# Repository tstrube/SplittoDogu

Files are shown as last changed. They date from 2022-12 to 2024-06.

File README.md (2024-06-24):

# SplittoDogu
QMK firmware for split keyboard with screens and encoders

This is a split keyboard with encoders for arrow keys, mouse wheels, page up/down, and undo/redo.
One of the two screens shows the active layer and status of Num and Caps. The other screen is for Bongo Cat...

It's also possible to use one side only. (Garming or Macro Keyboard)

Optional components: screens, encoder, buttons...

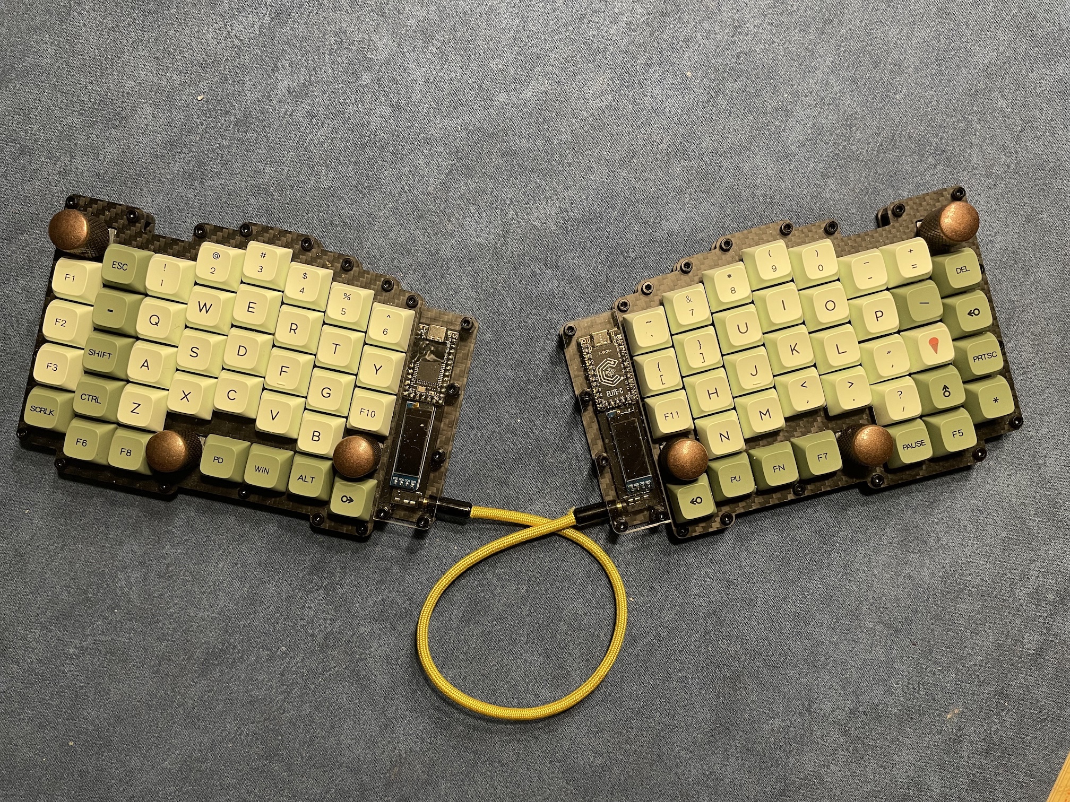
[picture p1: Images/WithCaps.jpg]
Splitto Dogu with Caps

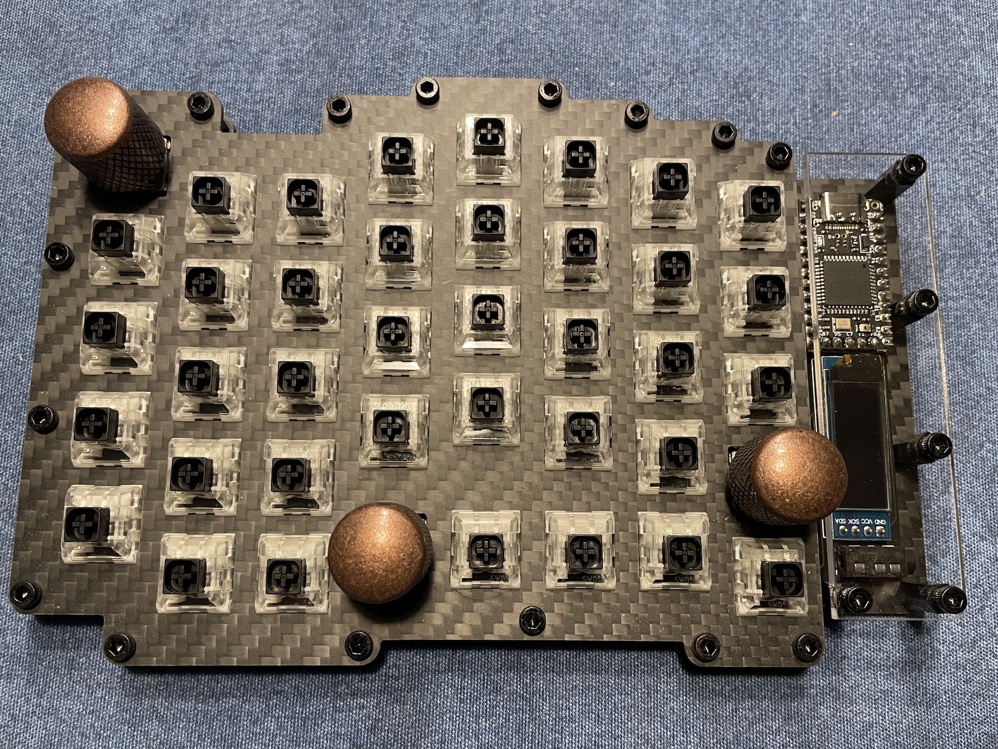
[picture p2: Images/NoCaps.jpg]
Splitto Dogu without Caps


## Layouts
There are two nearly identical default layouts. One for Windows and the other for MAC.
The differences are key combinations for undo/redo and other hotkeys.

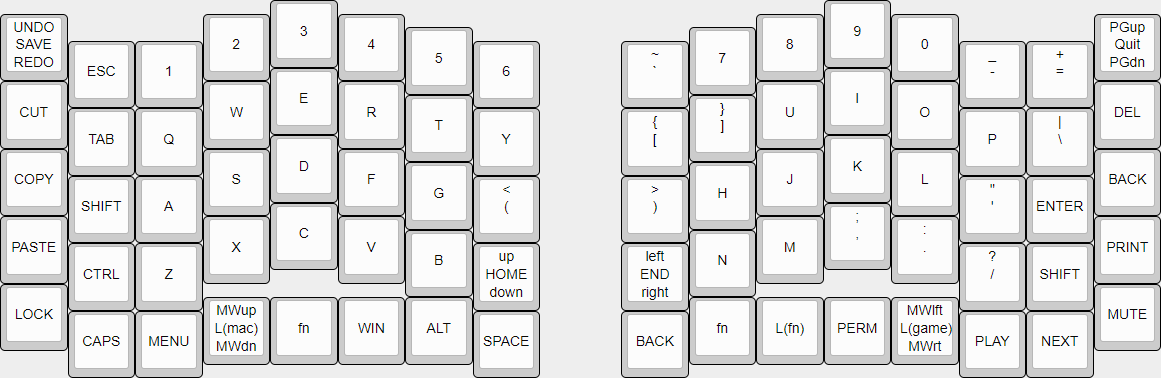
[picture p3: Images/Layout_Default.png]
Splitto Dogu Layout Default


Next is a layer for gaming, which shifts most buttons on the left half to the right by one key.
This is moves WASD to the optimal position.

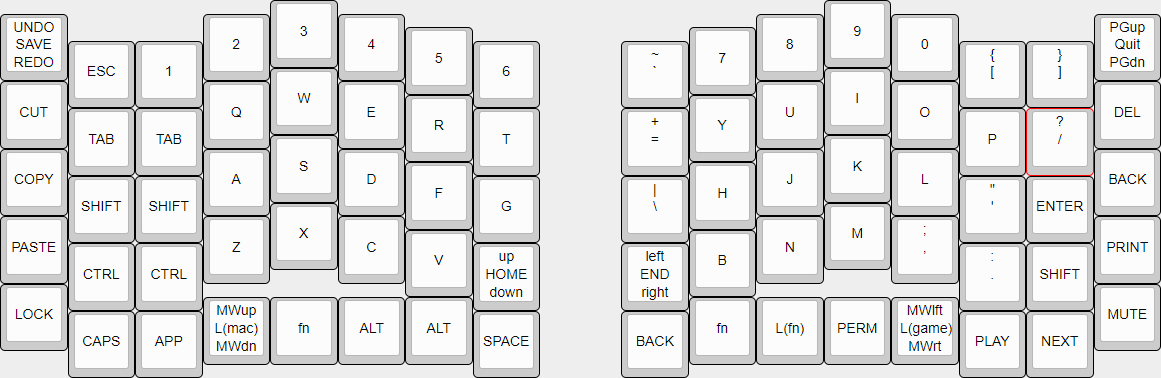
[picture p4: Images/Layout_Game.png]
Splitto Dogu Layout Game


The last layer FN is for F1 to F12, arrow keys, and the keypad.

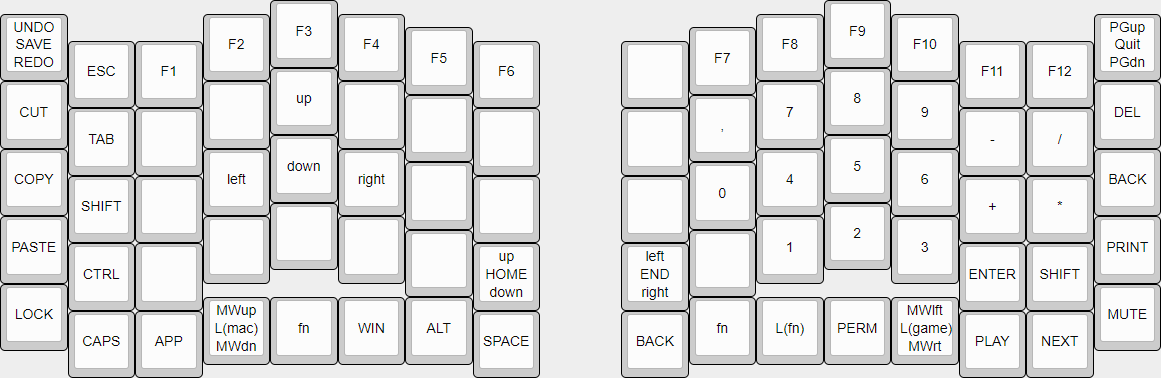
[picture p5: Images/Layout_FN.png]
Splitto Dogu Layout FN


## PCB
The PCB can be used for both sides. It's possible to use one half without the other.
So select which side a board is used for, bridge the jumper points under the OLED screen.
JP_L1 to JP_L6 for the left side, JP_R1 to JP_R6 for the right.
The Elite-C must be flipped depending on the side. (See images)

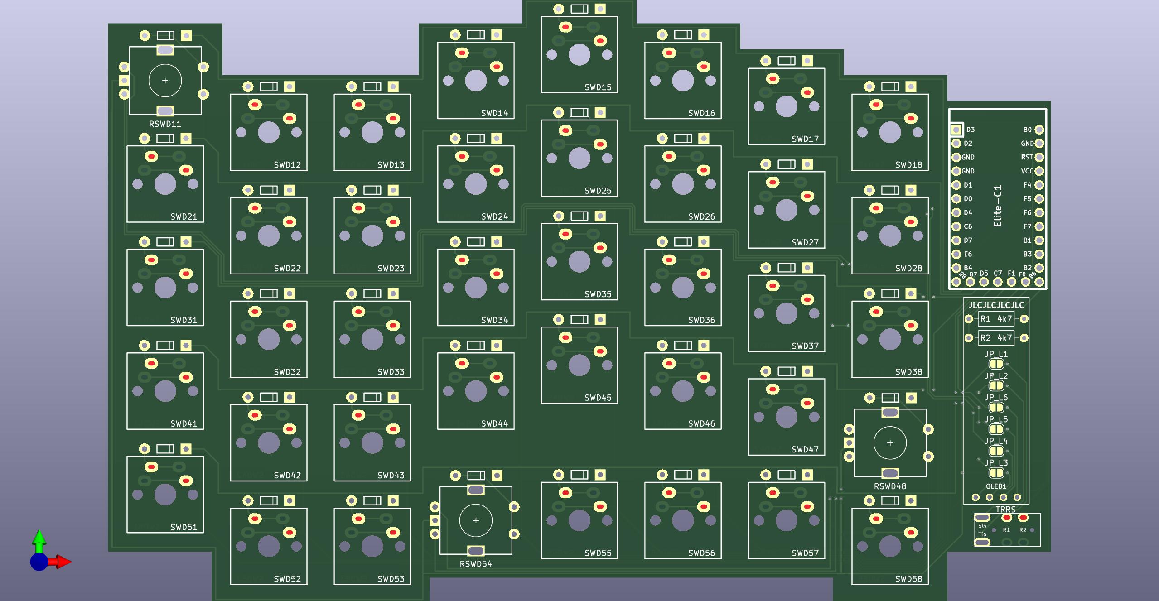
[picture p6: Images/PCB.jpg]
Splitto Dogu PCB

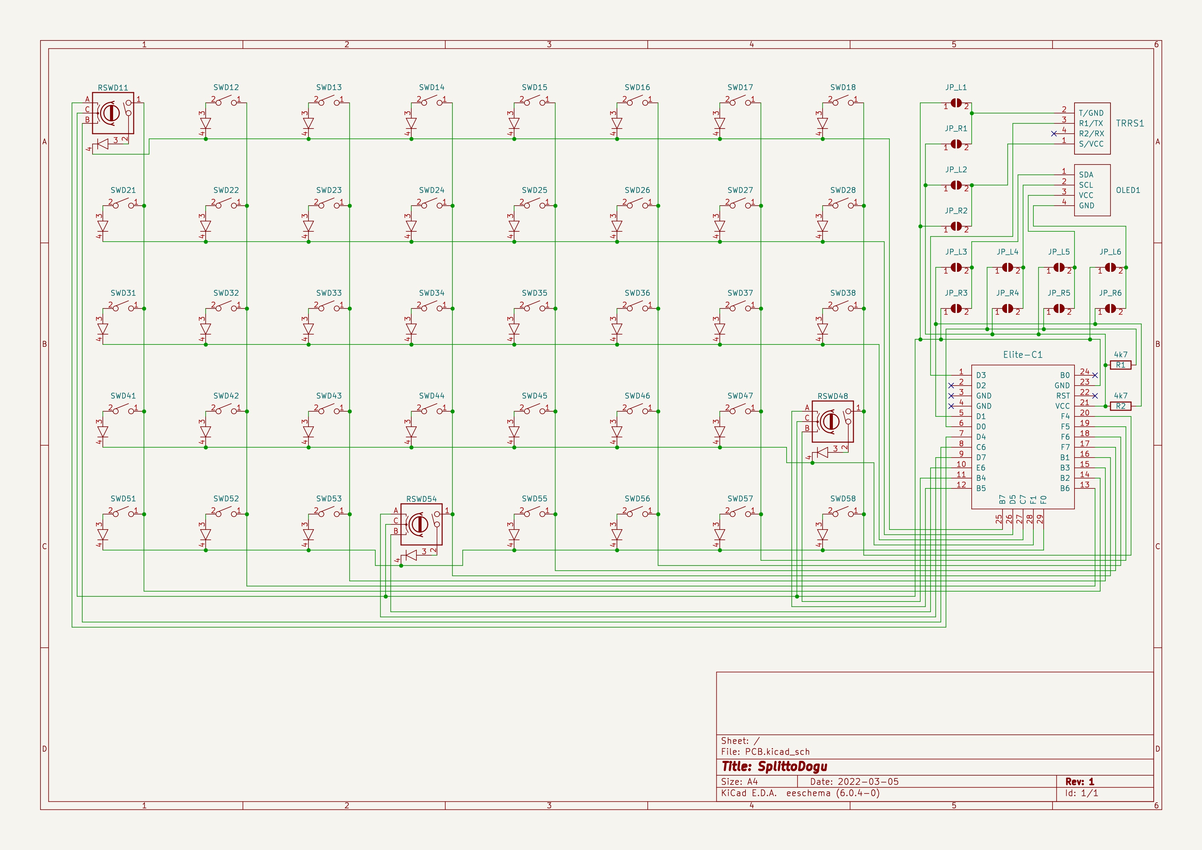
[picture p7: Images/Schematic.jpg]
Splitto Dogu Schematic


## Case
The case is a simple sandwich case with a clear part covering the chip and screen.
The main case uses 8mm standoffs, while the clear part uses 11mm. (See BOM)

## BOM
A list with all parts used and their approximate price as of March 2022.

## Crypto Donations

- **BTC:** bc1qqa9skjw0av0dnpzl53dhapgllw9nxpr3e3ncg6
- **DOGE:** D6Skk3K4H8KZWc7WcG69Ki5mkXc3f8pscc
- **ETH:** 0x7370eD840A690010eEF5726D71eEa54a9F45A202
- **SOL:** FipyS8kETFE8XRMkDez1nRRNe1n94Etws15UQfvzRsgg
- **XCH:** xch10t2jmnrnq8295pxqdtvn4pp5dgdcm7aar5usz0e4e57xyyjegtuqxwtq9z

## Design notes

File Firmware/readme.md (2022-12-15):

# splittodogu

splittodogu1
splittodogu2
splittodogu3

*A short description of the keyboard/project*

* Keyboard Maintainer: [Timo Strube](https://github.com/tstrube)
* Hardware Supported: [Custom PCB](https://github.com/tstrube/SplittoDogu)

Make example for this keyboard (after setting up your build environment):

    make splittodogu:default

Flashing example for this keyboard:

    make splittodogu:default:flash

See the [build environment setup](https://docs.qmk.fm/#/getting_started_build_tools) and the [make instructions](https://docs.qmk.fm/#/getting_started_make_guide) for more information. Brand new to QMK? Start with our [Complete Newbs Guide](https://docs.qmk.fm/#/newbs).

## Bootloader

Enter the bootloader in 3 ways:

* **Bootmagic reset**: Hold down the key at (0,0) in the matrix (usually the top left key or Escape) and plug in the keyboard
* **Keycode in layout**: Press the key mapped to `RESET` if it is available

## BongoCat
Screens show animated Bongo Cat on keypress

Original from pedker:
https://github.com/pedker/OLED-BongoCat-Revision

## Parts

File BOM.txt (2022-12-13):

Cost are for the position, rounded
Most positions are bulk purchases and calculated down

10 EUR  2 x PCB
40 EUR  2 x Elite-C
 5 EUR  2 x SSD1306 128X32 OLED
 1 EUR  2 x TTRS Jack PJ-320A
10 EUR  1 x TRRS cable, short
 5 EUR  6 x EC 11 Encoder /w button
 8 EUR  6 x Cap for EC 11
20 EUR 72 x MX type switch
 2 EUR 76 x 1N4148 Diode
 3 EUR 34 x M3 Hex Standoff  8mm
 1 EUR 10 x M3 Hex Standoff 12mm 
 5 EUR 88 x M3 Screw (max 5mm long)
 ? EUR  2 x 3D printed Sandwich Case
20 EUR  1 x Keycap set

Total 130 EUR

Optional
50 EUR  2 x Carbon Fiber Sandwich Case with Plexiglas cover

Total 180 EUR

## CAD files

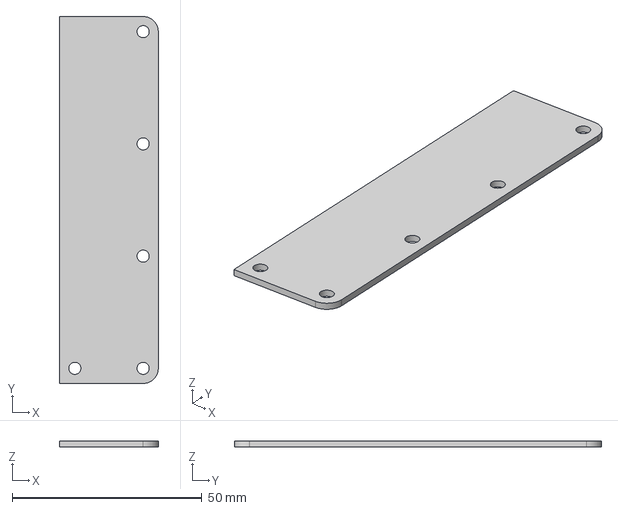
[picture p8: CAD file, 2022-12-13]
Case/Plexi.step
26.0 x 96.8 x 1.50 mm

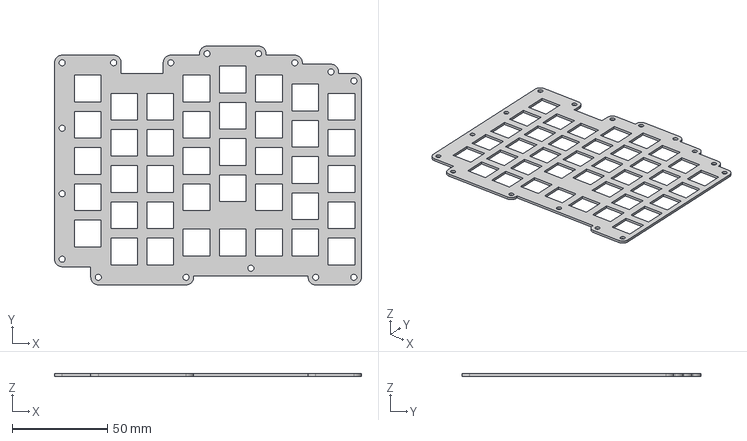
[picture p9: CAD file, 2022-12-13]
Case/Keys.step
161.0 x 125.2 x 1.50 mm

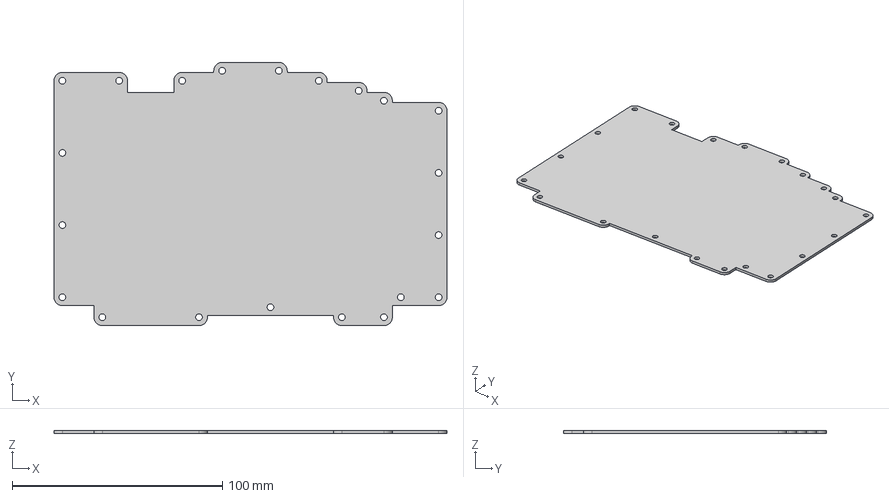
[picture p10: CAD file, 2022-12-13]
Case/Base.step
187.0 x 125.2 x 1.50 mm

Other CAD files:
Case/Base.dxf
Case/Base.stl
Case/Keys.dxf
Case/Keys.stl
Case/Plexi.dxf
Case/Plexi.stl

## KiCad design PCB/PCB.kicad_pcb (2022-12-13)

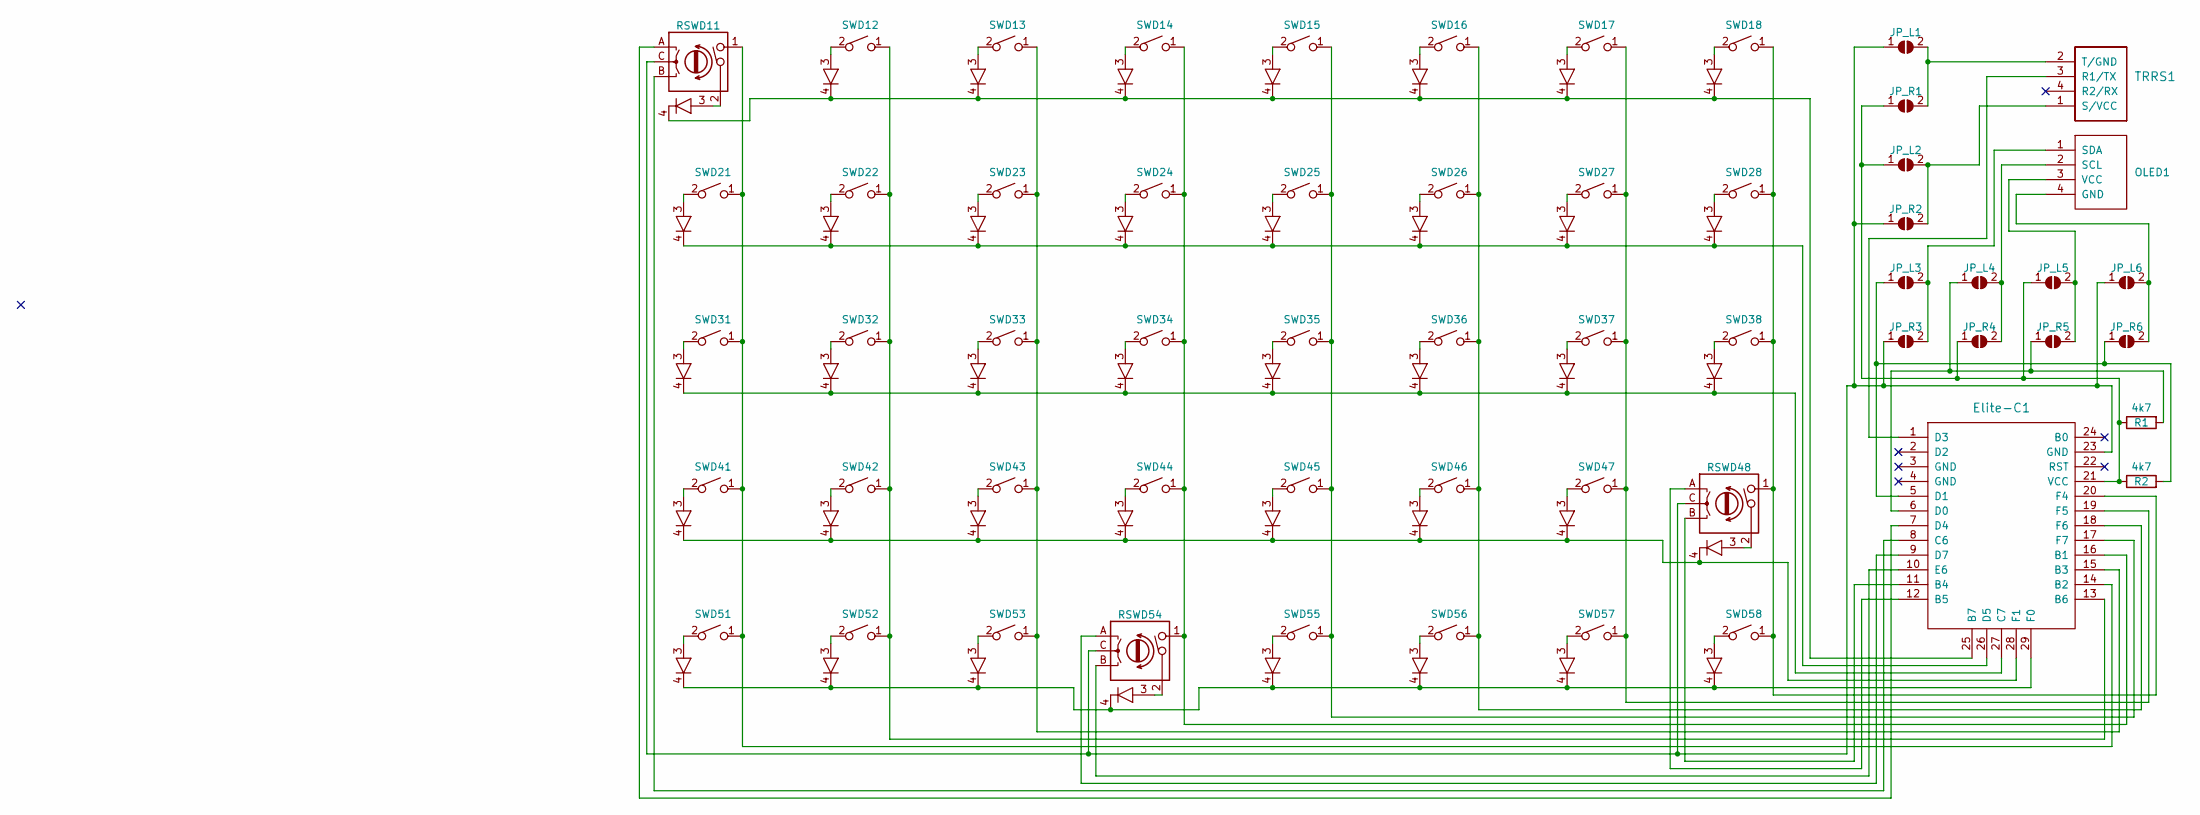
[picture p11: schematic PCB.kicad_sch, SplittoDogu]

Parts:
Elite-C1: Elite-C
JP_L1, JP_L2, JP_L3, JP_L4, JP_L5, JP_L6: SolderJumper_Open
JP_R1, JP_R2, JP_R3, JP_R4, JP_R5, JP_R6: SolderJumper_Open
OLED1: OLED
R1, R2: 4k7; R_Axial_DIN0207_L6.3mm_D2.5mm_P10.16mm_Horizontal
RSWD11, RSWD48, RSWD54: RotaryEncoder_Switch_Diode
SWD12, SWD13, SWD14, SWD15, SWD16, SWD17, SWD18, SWD21, SWD22, SWD23, SWD24, SWD25, SWD26, SWD27, SWD28, SWD31, SWD32, SWD33, SWD34, SWD35, SWD36, SWD37, SWD38, SWD41, SWD42, SWD43, SWD44, SWD45, SWD46, SWD47, SWD51, SWD52, SWD53, SWD55, SWD56, SWD57, SWD58: MX_Diode; MX
TRRS1: TRRS; TRRS-PJ-320A

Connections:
unnamed: Elite-C1.1 (D3), TRRS1.3 (R1/TX)
unnamed: Elite-C1.5 (D1), JP_L3.1, JP_R6.1, R2.2
unnamed: Elite-C1.6 (D0), JP_L4.1, JP_R5.1, R1.2
unnamed: Elite-C1.7 (D4), RSWD11.A
unnamed: Elite-C1.8 (C6), RSWD11.B
unnamed: Elite-C1.9 (D7), RSWD54.A
unnamed: Elite-C1.10 (E6), RSWD54.B
unnamed: Elite-C1.11 (B4), RSWD48.B
unnamed: Elite-C1.12 (B5), RSWD48.A
unnamed: Elite-C1.13 (B6), SWD12.1, SWD22.1, SWD32.1, SWD42.1, SWD52.1
unnamed: Elite-C1.14 (B2), RSWD11.1, SWD21.1, SWD31.1, SWD41.1, SWD51.1
unnamed: Elite-C1.15 (B3), SWD13.1, SWD23.1, SWD33.1, SWD43.1, SWD53.1
unnamed: Elite-C1.16 (B1), RSWD54.1, SWD14.1, SWD24.1, SWD34.1, SWD44.1
unnamed: Elite-C1.17 (F7), SWD15.1, SWD25.1, SWD35.1, SWD45.1, SWD55.1
unnamed: Elite-C1.18 (F6), SWD16.1, SWD26.1, SWD36.1, SWD46.1, SWD56.1
unnamed: Elite-C1.19 (F5), SWD17.1, SWD27.1, SWD37.1, SWD47.1, SWD57.1
unnamed: Elite-C1.20 (F4), RSWD48.1, SWD18.1, SWD28.1, SWD38.1, SWD58.1
unnamed: Elite-C1.21 (VCC), JP_L2.1, JP_L5.1, JP_R1.1, JP_R4.1, R1.1, R2.1
unnamed: Elite-C1.23 (GND), JP_L1.1, JP_L6.1, JP_R2.1, JP_R3.1, RSWD11.C, RSWD48.C, RSWD54.C
unnamed: Elite-C1.25 (B7), RSWD11.4, SWD12.4, SWD13.4, SWD14.4, SWD15.4, SWD16.4, SWD17.4, SWD18.4
unnamed: Elite-C1.26 (D5), SWD21.4, SWD22.4, SWD23.4, SWD24.4, SWD25.4, SWD26.4, SWD27.4, SWD28.4
unnamed: Elite-C1.27 (C7), SWD31.4, SWD32.4, SWD33.4, SWD34.4, SWD35.4, SWD36.4, SWD37.4, SWD38.4
unnamed: Elite-C1.28 (F1), RSWD48.4, SWD41.4, SWD42.4, SWD43.4, SWD44.4, SWD45.4, SWD46.4, SWD47.4
unnamed: Elite-C1.29 (F0), RSWD54.4, SWD51.4, SWD52.4, SWD53.4, SWD55.4, SWD56.4, SWD57.4, SWD58.4
unnamed: JP_L1.2, JP_R1.2, TRRS1.2 (T/GND)
unnamed: JP_L2.2, JP_R2.2, TRRS1.1 (S/VCC)
unnamed: JP_L3.2, JP_R3.2, OLED1.1 (SDA)
unnamed: JP_L4.2, JP_R4.2, OLED1.2 (SCL)
unnamed: JP_L5.2, JP_R5.2, OLED1.3 (VCC)
unnamed: JP_L6.2, JP_R6.2, OLED1.4 (GND)
unnamed: RSWD11.2, RSWD11.3
unnamed: RSWD48.2, RSWD48.3
unnamed: RSWD54.2, RSWD54.3
unnamed: SWD12.2, SWD12.3
unnamed: SWD13.2, SWD13.3
unnamed: SWD14.2, SWD14.3
unnamed: SWD15.2, SWD15.3
unnamed: SWD16.2, SWD16.3
unnamed: SWD17.2, SWD17.3
unnamed: SWD18.2, SWD18.3
unnamed: SWD21.2, SWD21.3
unnamed: SWD22.2, SWD22.3
unnamed: SWD23.2, SWD23.3
unnamed: SWD24.2, SWD24.3
unnamed: SWD25.2, SWD25.3
unnamed: SWD26.2, SWD26.3
unnamed: SWD27.2, SWD27.3
unnamed: SWD28.2, SWD28.3
unnamed: SWD31.2, SWD31.3
unnamed: SWD32.2, SWD32.3
unnamed: SWD33.2, SWD33.3
unnamed: SWD34.2, SWD34.3
unnamed: SWD35.2, SWD35.3
unnamed: SWD36.2, SWD36.3
unnamed: SWD37.2, SWD37.3
unnamed: SWD38.2, SWD38.3
unnamed: SWD41.2, SWD41.3
unnamed: SWD42.2, SWD42.3
unnamed: SWD43.2, SWD43.3
unnamed: SWD44.2, SWD44.3
unnamed: SWD45.2, SWD45.3
unnamed: SWD46.2, SWD46.3
unnamed: SWD47.2, SWD47.3
unnamed: SWD51.2, SWD51.3
unnamed: SWD52.2, SWD52.3
unnamed: SWD53.2, SWD53.3
unnamed: SWD55.2, SWD55.3
unnamed: SWD56.2, SWD56.3
unnamed: SWD57.2, SWD57.3
unnamed: SWD58.2, SWD58.3

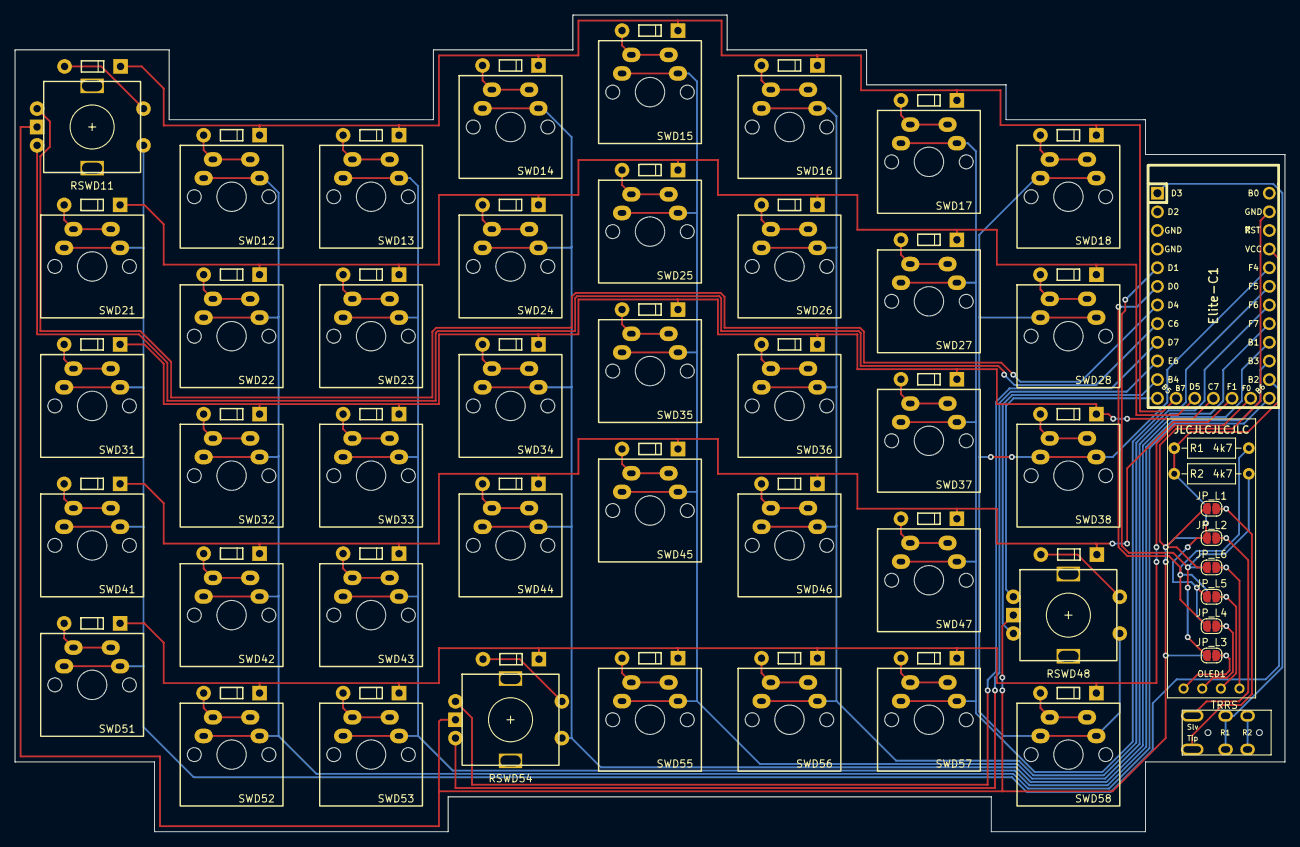
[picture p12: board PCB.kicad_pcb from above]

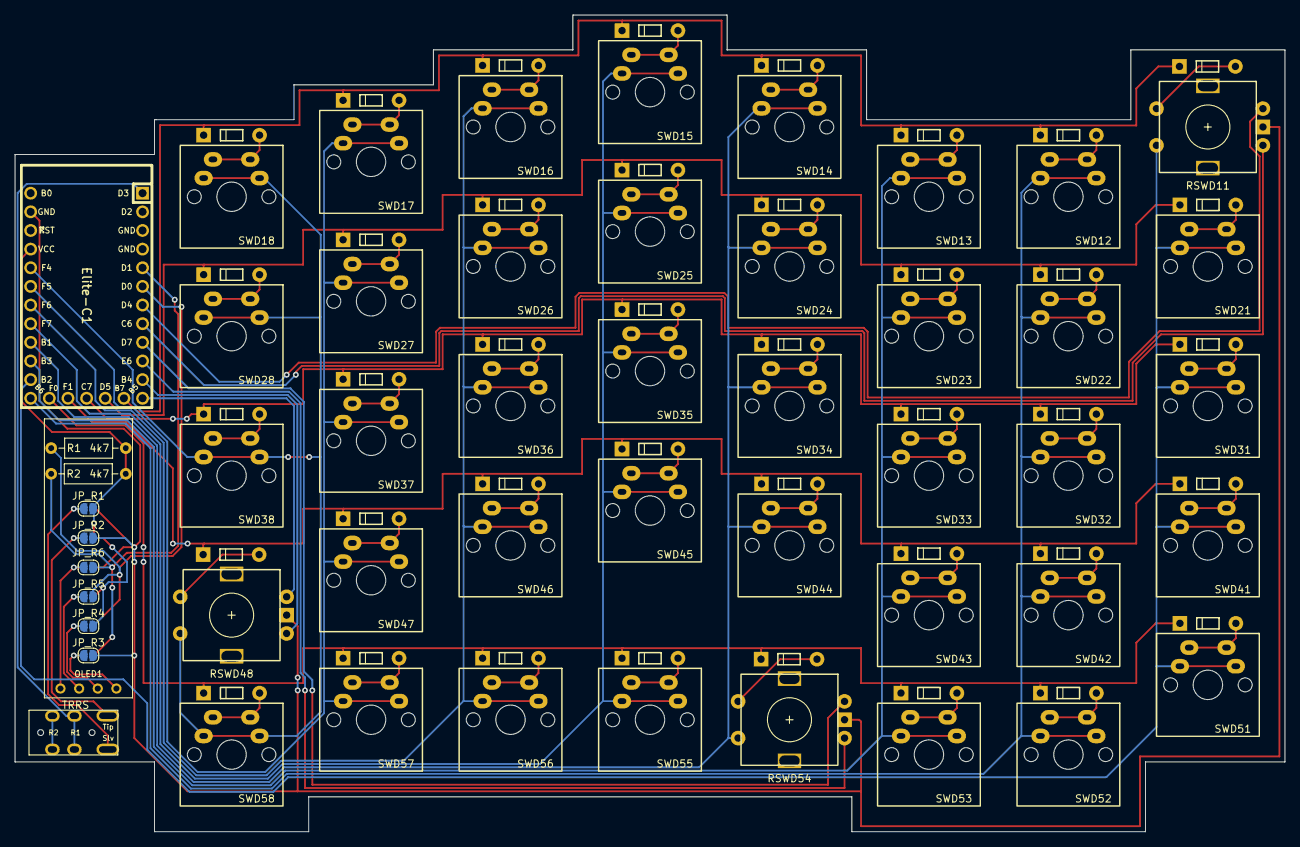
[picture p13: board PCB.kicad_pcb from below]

Board: 2 copper layers, 173.0 x 111.2 mm, 57 parts (6 on the bottom side), 70 nets.

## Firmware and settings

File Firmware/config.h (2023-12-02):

// Copyright 2022 Timo Strube (@tstrube)
// SPDX-License-Identifier: GPL-2.0-or-later

#pragma once

#define MATRIX_COLS 8
#define MATRIX_ROWS 10
#define MATRIX_COL_PINS { B2, B6, B3, B1, F7, F6, F5, F4 }
#define MATRIX_ROW_PINS { B7, D5, C7, F1, F0 }
#define MATRIX_COL_PINS_RIGHT { F4, F5, F6, F7, B1, B3, B6, B2 }

#define ENCODERS_PAD_A { C6, D7, B5 }
#define ENCODERS_PAD_B { D4, E6, B4 }

#define SOFT_SERIAL_PIN D3
#define SPLIT_LAYER_STATE_ENABLE
#define SPLIT_LED_STATE_ENABLE
#define SPLIT_MODS_ENABLE
#define SPLIT_OLED_ENABLE
#define SPLIT_TRANSPORT_MIRROR
#define SPLIT_USB_DETECT

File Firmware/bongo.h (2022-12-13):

#define ANIM_FRAME_DURATION 75 // how long each frame lasts in ms
#define ANIM_SIZE 636 // number of bytes in array, minimize for adequate firmware size, max is 1024
#define IDLE_FRAMES 5
#define IDLE_TIMEOUT 750 // the amount of time it takes to return to idle
#define TAP_FRAMES 2

enum anim_states
{
    Idle,
    Prep,
    Tap
};
uint8_t  anim_state         = Idle;
uint32_t idle_timeout_timer = 0;
uint32_t anim_timer         = 0;
uint8_t  current_idle_frame = 0;
uint8_t  current_tap_frame  = 0;

static const char PROGMEM idle_minimal[IDLE_FRAMES][ANIM_SIZE] = {
{
        0x00, 0x00, 0x00, 0x00, 0x00, 0x00, 0x00, 0x00, 0x00, 0x00, 0x00, 0x00, 0x00, 0x00, 0x00, 0x00,
        0x00, 0x00, 0x00, 0x00, 0x00, 0x00, 0x00, 0x00, 0x00, 0x00, 0x00, 0x00, 0x00, 0x00, 0x00, 0x00,
        0x00, 0x00, 0x00, 0x00, 0x00, 0x00, 0x00, 0x00, 0x00, 0x00, 0x00, 0x00, 0x00, 0x00, 0x00, 0x00,
        0x00, 0x00, 0x00, 0x80, 0x80, 0x40, 0x40, 0x40, 0x20, 0x20, 0x20, 0x20, 0x20, 0x18, 0x04, 0x02,
        0x01, 0x02, 0x04, 0x08, 0x10, 0x20, 0x20, 0x40, 0x40, 0x80, 0x80, 0x00, 0x00, 0x00, 0x00, 0x00,
        0x00, 0x00, 0x00, 0x00, 0x00, 0x00, 0x00, 0x00, 0x00, 0x00, 0x00, 0x00, 0x00, 0x00, 0x00, 0x00,
        0x00, 0x00, 0x00, 0x00, 0x00, 0x00, 0x00, 0x00, 0x00, 0x00, 0x00, 0x00, 0x00, 0x00, 0x00, 0x00,
        0x00, 0x00, 0x00, 0x00, 0x80, 0x80, 0x80, 0x80, 0x40, 0x40, 0x40, 0x40, 0x20, 0x20, 0x20, 0x20,
        0x00, 0x00, 0x00, 0x00, 0x00, 0x00, 0x00, 0x00, 0x00, 0x00, 0x00, 0x00, 0x00, 0x00, 0x00, 0x00,
        0x00, 0x00, 0x00, 0x00, 0x00, 0x00, 0x00, 0x00, 0x00, 0x00, 0x00, 0x00, 0x00, 0x00, 0x00, 0x00,
        0x00, 0x00, 0x00, 0x00, 0x00, 0x00, 0x00, 0x3f, 0xc1, 0x01, 0x01, 0x02, 0x02, 0x04, 0x04, 0x04,
        0x04, 0x02, 0x02, 0x01, 0x00, 0x00, 0x00, 0x00, 0x00, 0x00, 0x00, 0x00, 0x80, 0x00, 0x00, 0x40,
        0x80, 0x80, 0x40, 0x00, 0x00, 0x30, 0x30, 0x00, 0x00, 0x00, 0x00, 0x01, 0x02, 0x04, 0x04, 0x08,
        0x08, 0x10, 0x20, 0x40, 0x80, 0x80, 0x80, 0x80, 0x40, 0x40, 0x40, 0x40, 0x20, 0x20, 0x20, 0x20,
        0x10, 0x10, 0x10, 0x10, 0x08, 0x08, 0x08, 0x08, 0x04, 0x04, 0x04, 0x04, 0x02, 0x02, 0x02, 0x02,
        0x01, 0x01, 0x01, 0x01, 0x00, 0x00, 0x00, 0x00, 0x00, 0x00, 0x00, 0x00, 0x00, 0x00, 0x00, 0x00,
        0x00, 0x00, 0x00, 0x00, 0x00, 0x00, 0x00, 0x00, 0x00, 0x00, 0x00, 0x00, 0x00, 0x00, 0x00, 0x00,
        0x00, 0x00, 0x00, 0x00, 0x00, 0x00, 0x00, 0x00, 0x00, 0x00, 0x00, 0x00, 0x00, 0x00, 0x00, 0x00,
        0x00, 0x00, 0x00, 0x00, 0x00, 0x00, 0xe0, 0x18, 0x06, 0x01, 0x00, 0x00, 0x00, 0x00, 0x00, 0x00,
        0x00, 0x00, 0x00, 0x00, 0x00, 0x80, 0x83, 0x83, 0x40, 0x40, 0x40, 0x40, 0x20, 0x21, 0x21, 0x20,
        0x10, 0x10, 0x10, 0x10, 0x08, 0x08, 0x08, 0x08, 0x04, 0x04, 0x04, 0x04, 0x04, 0x08, 0x30, 0x40,
        0x80, 0x80, 0x00, 0x00, 0x01, 0x86, 0x98, 0x60, 0x00, 0x00, 0x00, 0x00, 0x00, 0x00, 0x00, 0x00,
        0x00, 0x00, 0x00, 0x00, 0x00, 0x00, 0x00, 0x00, 0x00, 0x00, 0x00, 0x00, 0x00, 0x00, 0x00, 0x00,
        0x00, 0x00, 0x00, 0x00, 0x00, 0x00, 0x00, 0x00, 0x00, 0x00, 0x00, 0x00, 0x00, 0x00, 0x00, 0x00,
        0x00, 0x00, 0x00, 0x00, 0x00, 0x00, 0x00, 0x00, 0x00, 0x00, 0x00, 0x00, 0x00, 0x00, 0x00, 0x00,
        0x00, 0x00, 0x00, 0x00, 0x80, 0x80, 0x80, 0x80, 0x40, 0x40, 0x40, 0x40, 0x20, 0x20, 0x20, 0x20,
        0x10, 0x10, 0x10, 0x10, 0x08, 0x0f, 0x08, 0x08, 0x04, 0x04, 0x04, 0x04, 0x02, 0x04, 0x08, 0x10,
        0x10, 0x20, 0x20, 0x40, 0x40, 0x41, 0x42, 0x24, 0x18, 0x00, 0x00, 0x00, 0x00, 0x00, 0x00, 0x00,
        0x00, 0x00, 0x00, 0x00, 0x00, 0x00, 0x00, 0x00, 0x00, 0x00, 0x00, 0x00, 0x00, 0x00, 0x00, 0x00,
        0x00, 0x00, 0x01, 0x01, 0x01, 0x00, 0x00, 0x00, 0x00, 0x00, 0x00, 0x00, 0x00, 0x00, 0x00, 0x00,
        0x00, 0x00, 0x00, 0x00, 0x00, 0x00, 0x00, 0x00, 0x00, 0x00, 0x00, 0x00, 0x00, 0x00, 0x00, 0x00,
        0x00, 0x00, 0x00, 0x00, 0x00, 0x00, 0x00, 0x00, 0x00, 0x00, 0x00, 0x00, 0x00, 0x00, 0x00, 0x00
    },
    {
        0x00, 0x00, 0x00, 0x00, 0x00, 0x00, 0x00, 0x00, 0x00, 0x00, 0x00, 0x00, 0x00, 0x00, 0x00, 0x00,
        0x00, 0x00, 0x00, 0x00, 0x00, 0x00, 0x00, 0x00, 0x00, 0x00, 0x00, 0x00, 0x00, 0x00, 0x00, 0x00,
        0x00, 0x00, 0x00, 0x00, 0x00, 0x00, 0x00, 0x00, 0x00, 0x00, 0x00, 0x00, 0x00, 0x00, 0x00, 0x00,
        0x00, 0x00, 0x00, 0x00, 0x00, 0x00, 0x80, 0x80, 0x40, 0x40, 0x40, 0x20, 0x10, 0x08, 0x04, 0x02,
        0x01, 0x02, 0x04, 0x08, 0x10, 0x20, 0x40, 0x80, 0x80, 0x00, 0x00, 0x00, 0x00, 0x00, 0x00, 0x00,
        0x00, 0x00, 0x00, 0x00, 0x00, 0x00, 0x00, 0x00, 0x00, 0x00, 0x00, 0x00, 0x00, 0x00, 0x00, 0x00,
        0x00, 0x00, 0x00, 0x00, 0x00, 0x00, 0x00, 0x00, 0x00, 0x00, 0x00, 0x00, 0x00, 0x00, 0x00, 0x00,
        0x00, 0x00, 0x00, 0x00, 0x80, 0x80, 0x80, 0x80, 0x40, 0x40, 0x40, 0x40, 0x20, 0x20, 0x20, 0x20,
        0x00, 0x00, 0x00, 0x00, 0x00, 0x00, 0x00, 0x00, 0x00, 0x00, 0x00, 0x00, 0x00, 0x00, 0x00, 0x00,
        0x00, 0x00, 0x00, 0x00, 0x00, 0x00, 0x00, 0x00, 0x00, 0x00, 0x00, 0x00, 0x00, 0x00, 0x00, 0x00,
        0x00, 0x00, 0x00, 0x00, 0x00, 0x00, 0x00, 0x3f, 0xc1, 0x01, 0x01, 0x02, 0x02, 0x04, 0x04, 0x04,
        0x04, 0x02, 0x02, 0x01, 0x01, 0x01, 0x00, 0x00, 0x00, 0x00, 0x00, 0x00, 0x00, 0x00, 0x00, 0x80,
        0x00, 0x00, 0x80, 0x00, 0x00, 0x60, 0x60, 0x00, 0x00, 0x01, 0x02, 0x04, 0x04, 0x08, 0x08, 0x10,
        0x10, 0x20, 0x20, 0x40, 0x80, 0x80, 0x80, 0x80, 0x40, 0x40, 0x40, 0x40, 0x20, 0x20, 0x20, 0x20,
        0x10, 0x10, 0x10, 0x10, 0x08, 0x08, 0x08, 0x08, 0x04, 0x04, 0x04, 0x04, 0x02, 0x02, 0x02, 0x02,
        0x01, 0x01, 0x01, 0x01, 0x00, 0x00, 0x00, 0x00, 0x00, 0x00, 0x00, 0x00, 0x00, 0x00, 0x00, 0x00,
        0x00, 0x00, 0x00, 0x00, 0x00, 0x00, 0x00, 0x00, 0x00, 0x00, 0x00, 0x00, 0x00, 0x00, 0x00, 0x00,
        0x00, 0x00, 0x00, 0x00, 0x00, 0x00, 0x00, 0x00, 0x00, 0x00, 0x00, 0x00, 0x00, 0x00, 0x00, 0x00,
        0x00, 0x00, 0x00, 0x00, 0x00, 0x00, 0xc0, 0x30, 0x0c, 0x03, 0x00, 0x00, 0x00, 0x00, 0x00, 0x00,
        0x00, 0x00, 0x00, 0x00, 0x00, 0x80, 0x86, 0x86, 0x40, 0x40, 0x40, 0x40, 0x21, 0x22, 0x22, 0x20,
        0x11, 0x11, 0x10, 0x10, 0x08, 0x08, 0x08, 0x08, 0x04, 0x04, 0x04, 0x04, 0x04, 0x08, 0x30, 0x40,
        0x80, 0x80, 0x00, 0x00, 0x01, 0x86, 0x98, 0x60, 0x00, 0x00, 0x00, 0x00, 0x00, 0x00, 0x00, 0x00,
        0x00, 0x00, 0x00, 0x00, 0x00, 0x00, 0x00, 0x00, 0x00, 0x00, 0x00, 0x00, 0x00, 0x00, 0x00, 0x00,
        0x00, 0x00, 0x00, 0x00, 0x00, 0x00, 0x00, 0x00, 0x00, 0x00, 0x00, 0x00, 0x00, 0x00, 0x00, 0x00,
        0x00, 0x00, 0x00, 0x00, 0x00, 0x00, 0x00, 0x00, 0x00, 0x00, 0x00, 0x00, 0x00, 0x00, 0x00, 0x00,
        0x00, 0x00, 0x00, 0x00, 0x80, 0x80, 0x80, 0x80, 0x40, 0x40, 0x40, 0x40, 0x20, 0x20, 0x20, 0x20,
        0x10, 0x10, 0x10, 0x10, 0x08, 0x0f, 0x08, 0x08, 0x04, 0x04, 0x04, 0x04, 0x02, 0x04, 0x08, 0x10,
        0x10, 0x20, 0x20, 0x40, 0x40, 0x41, 0x42, 0x24, 0x18, 0x00, 0x00, 0x00, 0x00, 0x00, 0x00, 0x00,
        0x00, 0x00, 0x00, 0x00, 0x00, 0x00, 0x00, 0x00, 0x00, 0x00, 0x00, 0x00, 0x00, 0x00, 0x00, 0x00,
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

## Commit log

2022-12-15 switch plus return in numpad
2022-12-15 update pcb image
